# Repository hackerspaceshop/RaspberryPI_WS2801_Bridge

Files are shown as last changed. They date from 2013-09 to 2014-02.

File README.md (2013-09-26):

RaspberryPI_WS2801_Bridge
=========================

Software for Raspberry PI to WS2801 Bridge 
/pcb  folder includes latest schematic and baord file (eagle)  + pdf
/software includes all the raspberry pi software
/image contains one big image file that you can directly dd to an SD card (min 4GB)

http://www.hackerspaceshop.com/ledstrips/raspberrypi-ws2801.html

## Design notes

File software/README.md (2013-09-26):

this is the blinkenpi project

it implements a WS2801 blinken interface for the raspberry pi 2 ws2801 bridge found here: http://www.hackerspaceshop.com/raspberrypi-things/raspberrypi-ws2801.html

the hardware SPI is used and we need py-spidev for that.
a compiled spidev.so is included in this folder.

you can compile your own libraries for spidev if you like to. 
we found the sources here:

https://github.com/doceme/py-spidev
thanks doceme!

have fun!
-flo

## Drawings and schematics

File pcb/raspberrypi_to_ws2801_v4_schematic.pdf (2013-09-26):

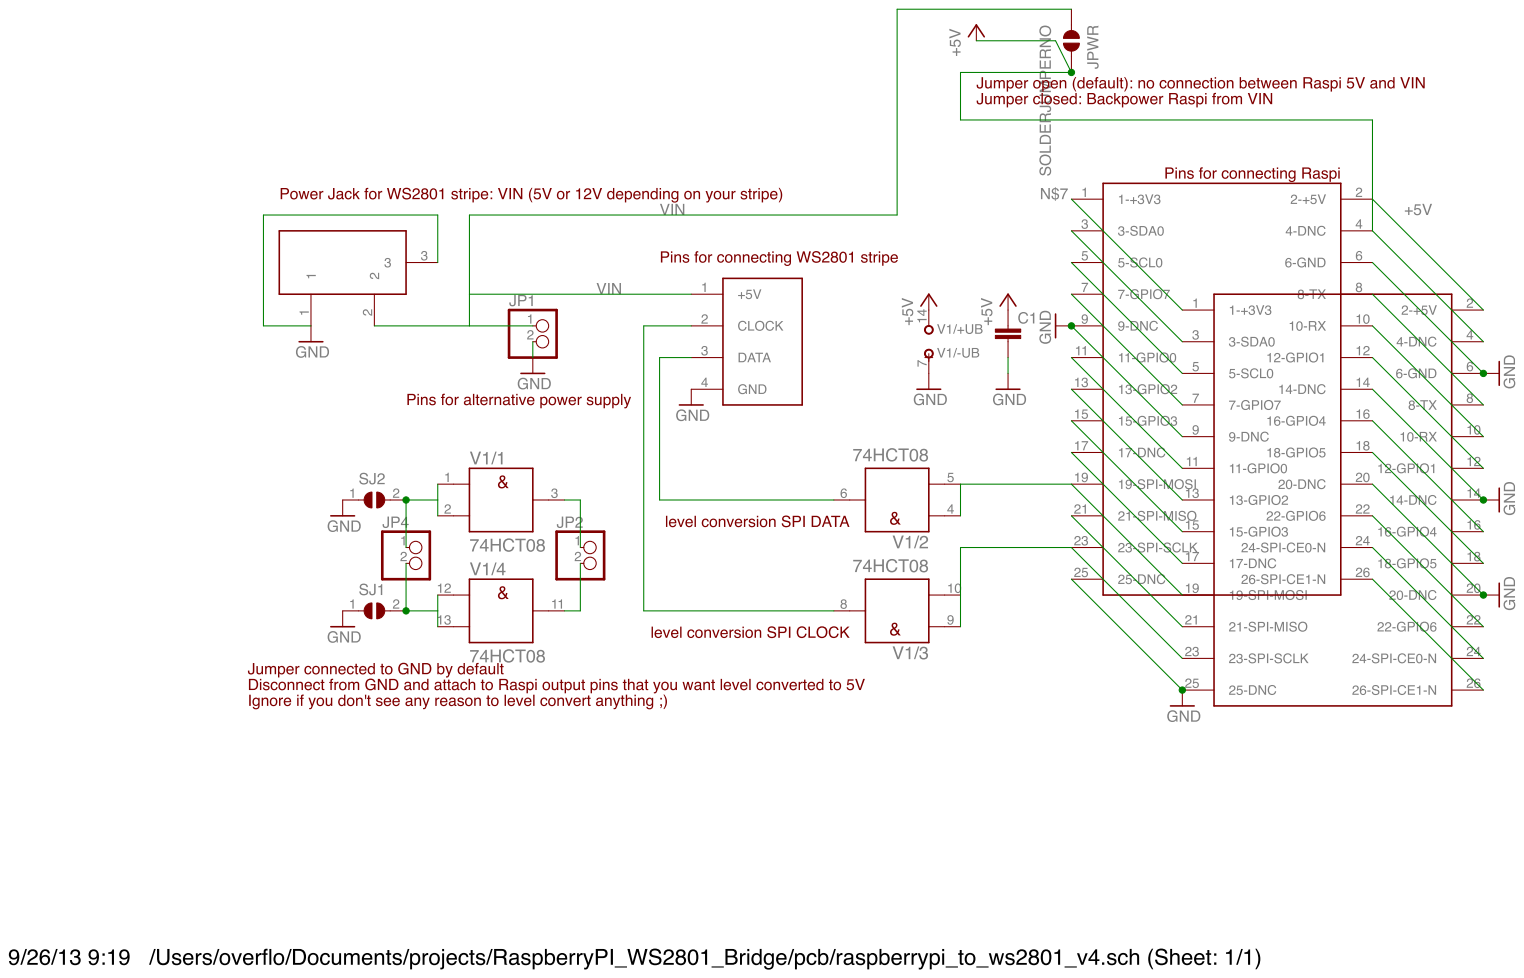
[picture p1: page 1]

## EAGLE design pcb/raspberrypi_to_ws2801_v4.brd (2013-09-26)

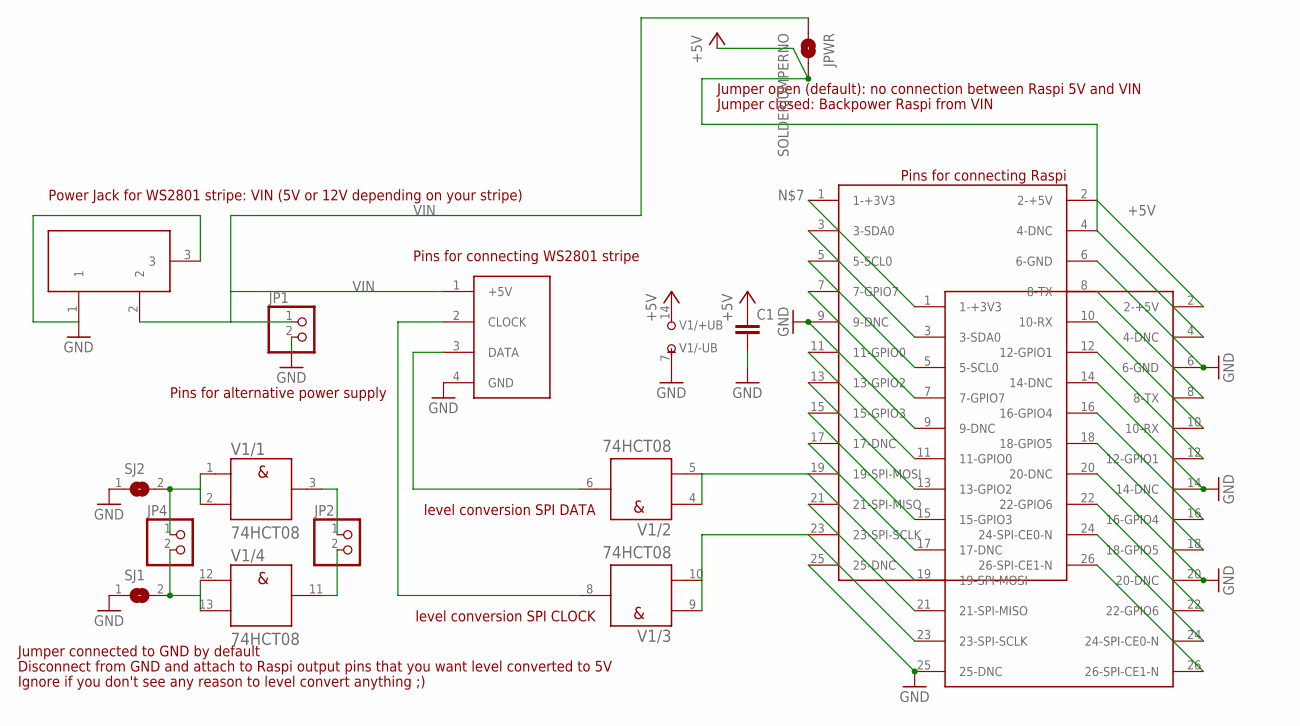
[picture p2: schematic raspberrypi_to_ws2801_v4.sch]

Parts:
C1: C-EU025-024X044; C025-024X044
JP1, JP2, JP4: PINHD-1X2; 1X02
JPWR: SOLDERJUMPERNO; SJ_2S-NO
SJ1, SJ2: SJ
U$1, U$2: RASPBERRY-PI
U$3: W2801STRIP; 1X04
U$5: DC21MMX; DC-21MM
V1: 74HCT08; DIL14

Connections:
+5V: C1.1, JPWR.2, U$1.2 (2-+5V), U$1.4 (4-DNC), U$2.2 (2-+5V), U$2.4 (4-DNC), V1.14 (+UB)
GND: C1.2, JP1.2, SJ1.1, SJ2.1, U$1.6 (6-GND), U$1.9 (9-DNC), U$1.14 (14-DNC), U$1.20 (20-DNC), U$1.25 (25-DNC), U$2.6 (6-GND), U$2.9 (9-DNC), U$2.14 (14-DNC), U$2.20 (20-DNC), U$2.25 (25-DNC), U$3.4 (GND), U$5.1, U$5.3, V1.7 (-UB)
unnamed: U$1.19 (19-SPI-MOSI), U$2.19 (19-SPI-MOSI), V1.4 (A), V1.5 (B)
unnamed: U$3.2 (CLOCK), V1.8 (Y)
unnamed: U$1.23 (23-SPI-SCLK), U$2.23 (23-SPI-SCLK), V1.9 (A), V1.10 (B)
unnamed: U$1.3 (3-SDA0), U$2.3 (3-SDA0)
unnamed: U$1.5 (5-SCL0), U$2.5 (5-SCL0)
unnamed: U$1.1 (1-+3V3), U$2.1 (1-+3V3)
unnamed: U$1.7 (7-GPIO7), U$2.7 (7-GPIO7)
unnamed: U$1.8 (8-TX), U$2.8 (8-TX)
unnamed: U$1.10 (10-RX), U$2.10 (10-RX)
unnamed: U$1.11 (11-GPIO0), U$2.11 (11-GPIO0)
unnamed: U$1.12 (12-GPIO1), U$2.12 (12-GPIO1)
unnamed: U$1.13 (13-GPIO2), U$2.13 (13-GPIO2)
unnamed: U$1.15 (15-GPIO3), U$2.15 (15-GPIO3)
unnamed: U$1.16 (16-GPIO4), U$2.16 (16-GPIO4)
unnamed: U$1.17 (17-DNC), U$2.17 (17-DNC)
unnamed: U$1.18 (18-GPIO5), U$2.18 (18-GPIO5)
unnamed: U$1.21 (21-SPI-MISO), U$2.21 (21-SPI-MISO)
unnamed: U$1.22 (22-GPIO6), U$2.22 (22-GPIO6)
unnamed: U$1.24 (24-SPI-CE0-N), U$2.24 (24-SPI-CE0-N)
unnamed: U$1.26 (26-SPI-CE1-N), U$2.26 (26-SPI-CE1-N)
unnamed: U$3.3 (DATA), V1.6 (Y)
unnamed: JP2.1, V1.3 (Y)
unnamed: JP2.2, V1.11 (Y)
unnamed: JP4.2, SJ1.2, V1.12 (A), V1.13 (B)
unnamed: JP4.1, SJ2.2, V1.1 (A), V1.2 (B)
VIN: JP1.1, JPWR.1, U$3.1 (+5V), U$5.2

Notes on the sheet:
Jumper connected to GND by default
Jumper open (default): no connection between Raspi 5V and VIN
Power Jack for WS2801 stripe: VIN (5V or 12V depending on your stripe)
Disconnect from GND and attach to Raspi output pins that you want level converted to 5V
Jumper closed: Backpower Raspi from VIN
Pins for alternative power supply
Pins for connecting WS2801 stripe
Pins for connecting Raspi
level conversion SPI DATA
level conversion SPI CLOCK
Ignore if you don't see any reason to level convert anything ;)

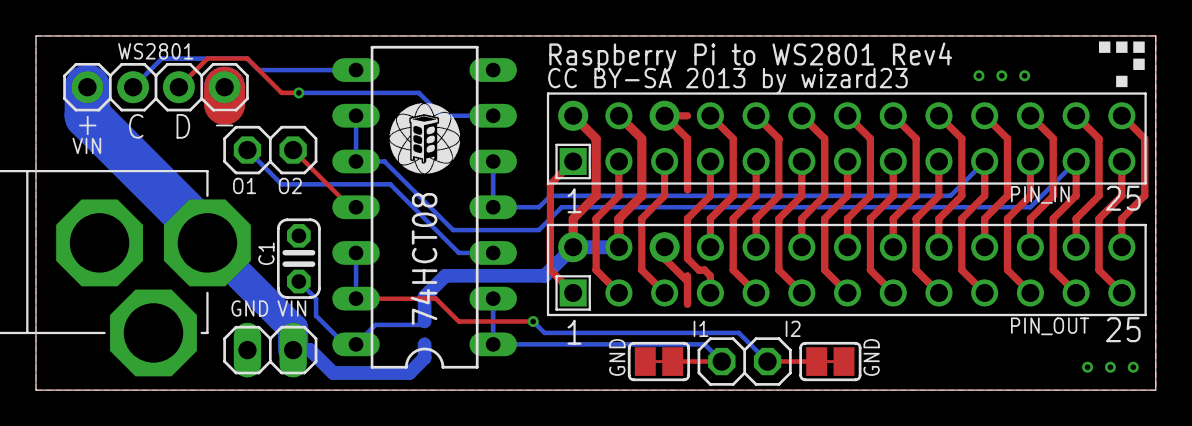
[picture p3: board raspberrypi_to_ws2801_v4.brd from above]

Board: 2 copper layers, 62.2 x 19.7 mm, 13 parts (1 on the bottom side), 28 nets.

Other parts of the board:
U$4: METALAB_SMALL

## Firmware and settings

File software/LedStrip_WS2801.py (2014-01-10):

# Simple Python Library for accessing WS2801 LED stripes
# Copyright (C) 2013  Philipp Tiefenbacher <wizards23@gmail.com>
#
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
# For more information about this project please visit:
# http://www.hackerspaceshop.com/ledstrips/raspberrypi-ws2801.html

import spidev


class LedStrip_WS2801(object):
    """Access to SPI with python spidev library."""
    # spiDevice has format [
    def __init__(self, nLeds, nBuffers=1):
        self.spi = spidev.SpiDev()  # create spi object
        self.spi.open(0, 1)
        self.spi.max_speed_hz = 1000000
        self.nLeds = nLeds
        self.nBuffers = nBuffers
        self.buffers = []
        for i in range(0, nBuffers):
            ba = []
            for l in range(0, nLeds):
                ba.extend([0, 0, 0])
            self.buffers.append(ba)

    def close(self):
        if (self.spi != None):
            self.spi.close()
            self.spi = None

    def update(self, bufferNr=0):
        self.spi.writebytes(self.buffers[bufferNr])

    def setAll(self, color, bufferNr=0):
        for i in range(0, self.nLeds):
            self.setPixel(i, color, bufferNr)

    def setPixel(self, index, color, bufferNr=0):
        self.buffers[bufferNr][index * 3:index * 3 + 3] = (color[0], color[2], color[1])


class LedStrip_WS2801_FileBased(LedStrip_WS2801):
    """Filebased acces to SPI."""
    def __init__(self, nLeds, spiDevice, nBuffers=1):
        self.spi = open(spiDevice, "w")
        self.nLeds = nLeds
        self.nBuffers = nBuffers
        self.buffers = []
        for i in range(0, nBuffers):
            ba = bytearray()
            for l in range(0, nLeds):
                ba.extend([0, 0, 0])
            self.buffers.append(ba)

    def update(self, bufferNr=0):
        self.spi.write(self.buffers[bufferNr])
        self.spi.flush()

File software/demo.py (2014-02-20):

# Simple Example for accessing WS2801 LED stripes
# Copyright (C) 2013  Philipp Tiefenbacher <wizards23@gmail.com>
#
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
# For more information about this project please visit:
# http://www.hackerspaceshop.com/ledstrips/raspberrypi-ws2801.html

import math
import sys
import time

from LedStrip_WS2801 import LedStrip_WS2801, LedStrip_WS2801_FileBased


def mySin(a, min, max):
    return min + ((max - min) / 2.) * (math.sin(a) + 1)


def rainbow(a):
    intense = 255
    return [int(mySin(a, 0, intense)), int(mySin(a + math.pi / 2, 0, intense)), int(mySin(a + math.pi, 0, intense))]


def fillAll(ledStrip, color, sleep):
    for i in range(0, ledStrip.nLeds):
        ledStrip.setPixel(i, color)
        ledStrip.update()
        time.sleep(sleep)


def rainbowAll(ledStrip, times, sleep):
    for t in range(0, times):
        for i in range(0, ledStrip.nLeds):
            ledStrip.setPixel(i, rainbow((1.1 * math.pi * (i + t)) / ledStrip.nLeds))
        ledStrip.update()
        if (sleep != 0):
            time.sleep(sleep)


def antialisedPoint(ledStrip, color, step, dscale, sleep=0):
    rr = color[0]
    gg = color[1]
    bb = color[2]
    screenOffset = int(1.0 / (step * dscale)) + 1
    for j in range(-screenOffset, int(ledStrip.nLeds / step + screenOffset)):
        for i in range(0, ledStrip.nLeds):
            delta = 1 - abs(i - j * step) * dscale
            if delta < 0:
                delta = 0
            ledStrip.setPixel(i, [int(delta * rr), int(delta * gg), int(delta * bb)])
        ledStrip.update()
        #   time.sleep(sleep)


def knight_rider(ledStrip, trail_nb_leds=3, color=[255, 0, 0], times=5, sleep=0.08):
    if trail_nb_leds > ledStrip.nLeds or trail_nb_leds <= 0:
        raise ValueError("Wrong trail_nb_leds value")
    black_color = [0, 0, 0]

    for i in range(times):
        # left to right
        for i in range(ledStrip.nLeds + trail_nb_leds):
            ledStrip.setAll(black_color)
            for j in range(min(i + 1, trail_nb_leds)):
                if i - j <= ledStrip.nLeds:
                    ledStrip.setPixel(index=i - j, color=[x / max((j * 8), 1) for x in color]) #  division is to fake lower brightness
            ledStrip.update()
            time.sleep(sleep)

        # right to left
        for i in reversed(range(-trail_nb_leds, ledStrip.nLeds)):
            ledStrip.setAll(black_color)
            for j in range(min(ledStrip.nLeds - i + 1, trail_nb_leds)):
                if i + j >= 0:
                    ledStrip.setPixel(index=i + j, color=[x / max((j * 8), 1) for x in color]) #  division is to fake lower brightness
            ledStrip.update()
            time.sleep(sleep)

        time.sleep(0.7)


if __name__ == '__main__':
    if len(sys.argv) == 1:
        nrOfleds = 160
    else:
        nrOfleds = int(sys.argv[1])
    delayTime = 0.01

    # oldStrip = LedStrip_WS2801_FileBased(nrOfleds, "/dev/spidev0.0")
    # fillAll(oldStrip, [255, 0, 0], delayTime)
    # oldStrip.close()

    ledStrip = LedStrip_WS2801(nrOfleds)

    while 1:
        fillAll(ledStrip, [0, 255, 0], delayTime)
        rainbowAll(ledStrip, 200, 0.01)
        fillAll(ledStrip, [255, 0, 0], 0.01)
        fillAll(ledStrip, [0, 255, 0], 0.01)
        fillAll(ledStrip, [0, 0, 255], 0.01)
        antialisedPoint(ledStrip, [255, 0, 0], 0.5, 0.3)
        antialisedPoint(ledStrip, [0, 255, 0], 0.5, 0.3)
        antialisedPoint(ledStrip, [0, 0, 255], 0.5, 0.3)
        rainbowAll(ledStrip, 500, 0.01)
        knight_rider(ledStrip)

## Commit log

2013-03-22 added scematic and pcb with comments :)
    [raspberrypi_to_ws2801_v3.brd, raspberrypi_to_ws2801_v3.sch]
2013-09-26 added v4 schematic and SDcard image, software ported to spidev
    [raspberrypi_to_ws2801_v3.brd, raspberrypi_to_ws2801_v3.sch, raspberrypi_to_ws2801_v4.brd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]
2013-09-26 added spidev.so from py-spi
2013-11-10 update demo to take number of leds as an argument
2013-11-10 fix 'fillAll' assumed led count of 25
    [demo.py]
2014-01-10 Added Old Filebased (non SPI) import for backwards compatibility

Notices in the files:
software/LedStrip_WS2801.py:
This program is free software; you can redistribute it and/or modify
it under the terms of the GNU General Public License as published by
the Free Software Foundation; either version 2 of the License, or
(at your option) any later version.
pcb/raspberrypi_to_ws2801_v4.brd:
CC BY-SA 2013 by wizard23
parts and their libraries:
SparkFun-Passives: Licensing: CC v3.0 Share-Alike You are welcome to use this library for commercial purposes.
